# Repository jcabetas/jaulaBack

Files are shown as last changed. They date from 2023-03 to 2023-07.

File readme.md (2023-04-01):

# Alimentador de gatos

## Sistema operativo
ChibiOS/RT port for ARM-Cortex-M4 STM32F411.

## uControlador
Datos en https://stm32-base.org/boards/STM32F411CEU6-WeAct-Black-Pill-V2.0.html

## Conexiones
- A1: Sensor 1
- A2: Sensor 2
- A2: TX2 (a RX Configuracion)
- A3: RX2 (a TX Configuracion)
- A9: TX1 (a GPS)
- A10: RX1 (a GPS)
- B0: ADC in divide Ubat por 220/(220+91)
- B8: PWM para Servo
- B13: ONGPS
- B14: ONSERVO
- B15: ON-AD

w25q16
- CS -   PA4
- SCK -  PA5    SPI1_SCK
- MISO - PA6    SPI1_MISO
- MOSI - PA7    SPI1_MOSI

## Parametros
* Las configuraciones se guardan en flash

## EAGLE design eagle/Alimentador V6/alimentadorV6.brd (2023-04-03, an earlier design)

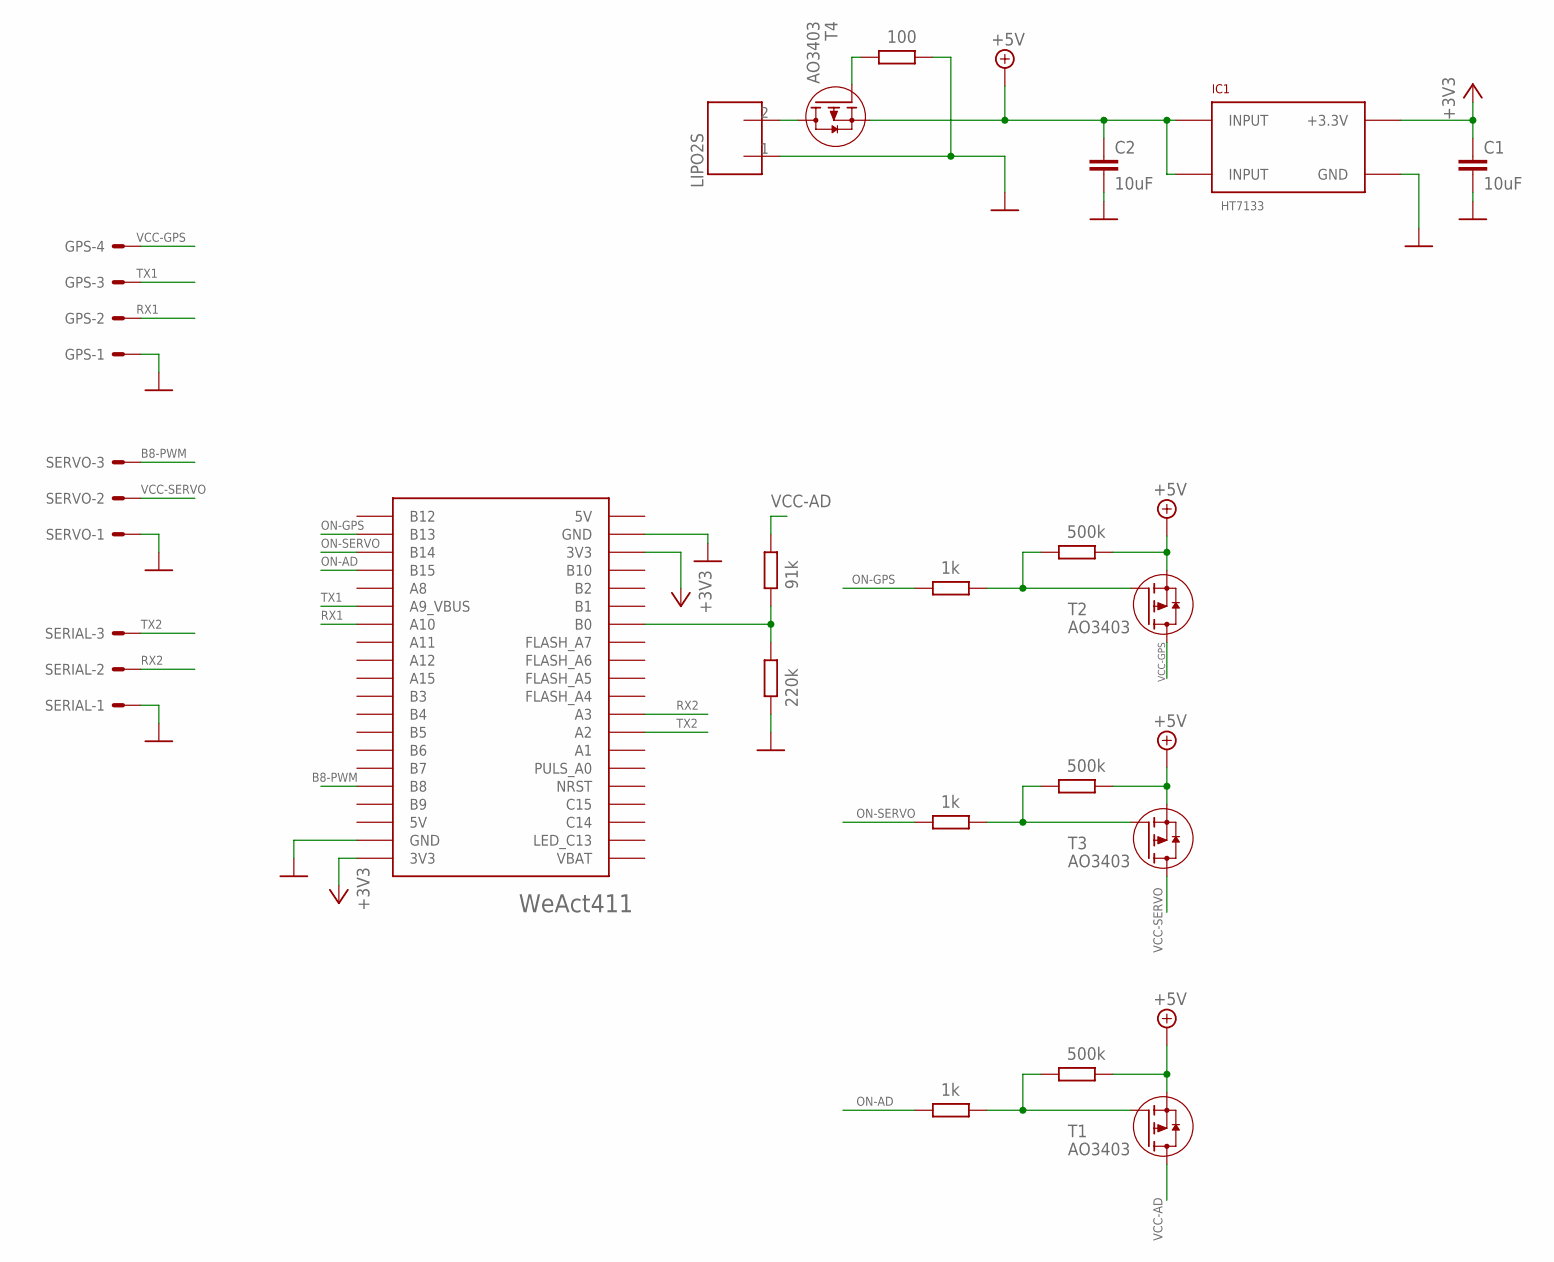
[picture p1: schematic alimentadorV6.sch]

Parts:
C1, C2: 10uF; C1206
GPS: 22-27-2041-04; 6410-04
IC1: HT7133; SOT89
LIPO2S: CONECTOR_2P-3.81; CON2P-3.81
R1, R5, R11: 500k; R1206
R2: 220k; R1206
R3: 91k; R1206
R4, R6, R12: 1k; R1206
R7: 100; R1206
SERIAL: 22-27-2031-03; 6410-03
SERVO: 22-27-2031-03; 6410-03
T1, T2, T3, T4: AO3403; SOT23
U$2: WEACT411

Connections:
+3V3: C1.1, IC1.3 (+3.3V), U$2.3V3@1 (3V3), U$2.3V3@2 (3V3)
+5V: C2.1, IC1.2 (INPUT), IC1.4 (INPUT), R1.2, R5.2, R11.2, T1.2 (S), T2.2 (S), T3.2 (S), T4.2 (S)
B8-PWM: SERVO.3, U$2.B8
GND: C1.2, C2.2, GPS.1, IC1.1 (GND), LIPO2S.1, R2.2, R7.2, SERIAL.1, SERVO.1, U$2.GND@1 (GND), U$2.GND@2 (GND)
unnamed: LIPO2S.2, T4.3 (D)
unnamed: R2.1, R3.2, U$2.B0
unnamed: R7.1, T4.1 (G)
unnamed: R1.1, R4.2, T2.1 (G)
unnamed: R11.1, R12.2, T1.1 (G)
unnamed: R5.1, R6.2, T3.1 (G)
ON-AD: R12.1, U$2.B15
ON-GPS: R4.1, U$2.B13
ON-SERVO: R6.1, U$2.B14
RX1: GPS.2, U$2.A10
RX2: SERIAL.2, U$2.A3
TX1: GPS.3, U$2.A9 (A9_VBUS)
TX2: SERIAL.3, U$2.A2
VCC-AD: R3.1, T1.3 (D)
VCC-GPS: GPS.4, T2.3 (D)
VCC-SERVO: SERVO.2, T3.3 (D)

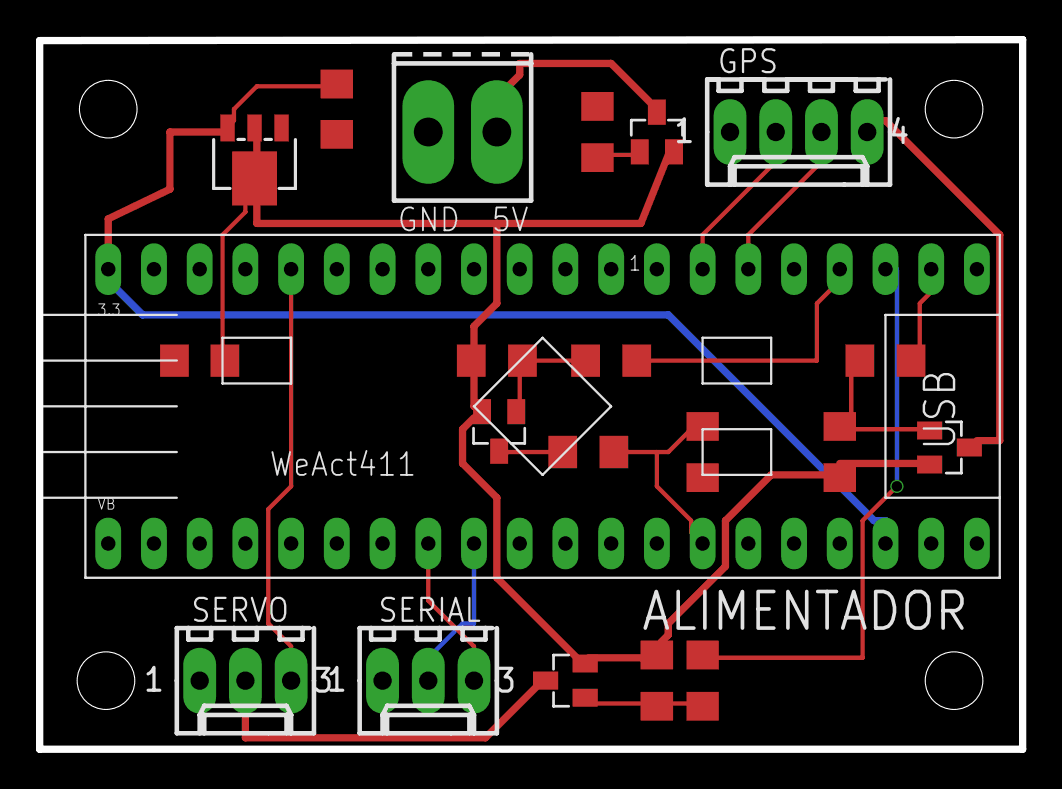
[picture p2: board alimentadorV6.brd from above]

Board: 2 copper layers, 54.6 x 39.4 mm, 21 parts (0 on the bottom side), 20 nets.

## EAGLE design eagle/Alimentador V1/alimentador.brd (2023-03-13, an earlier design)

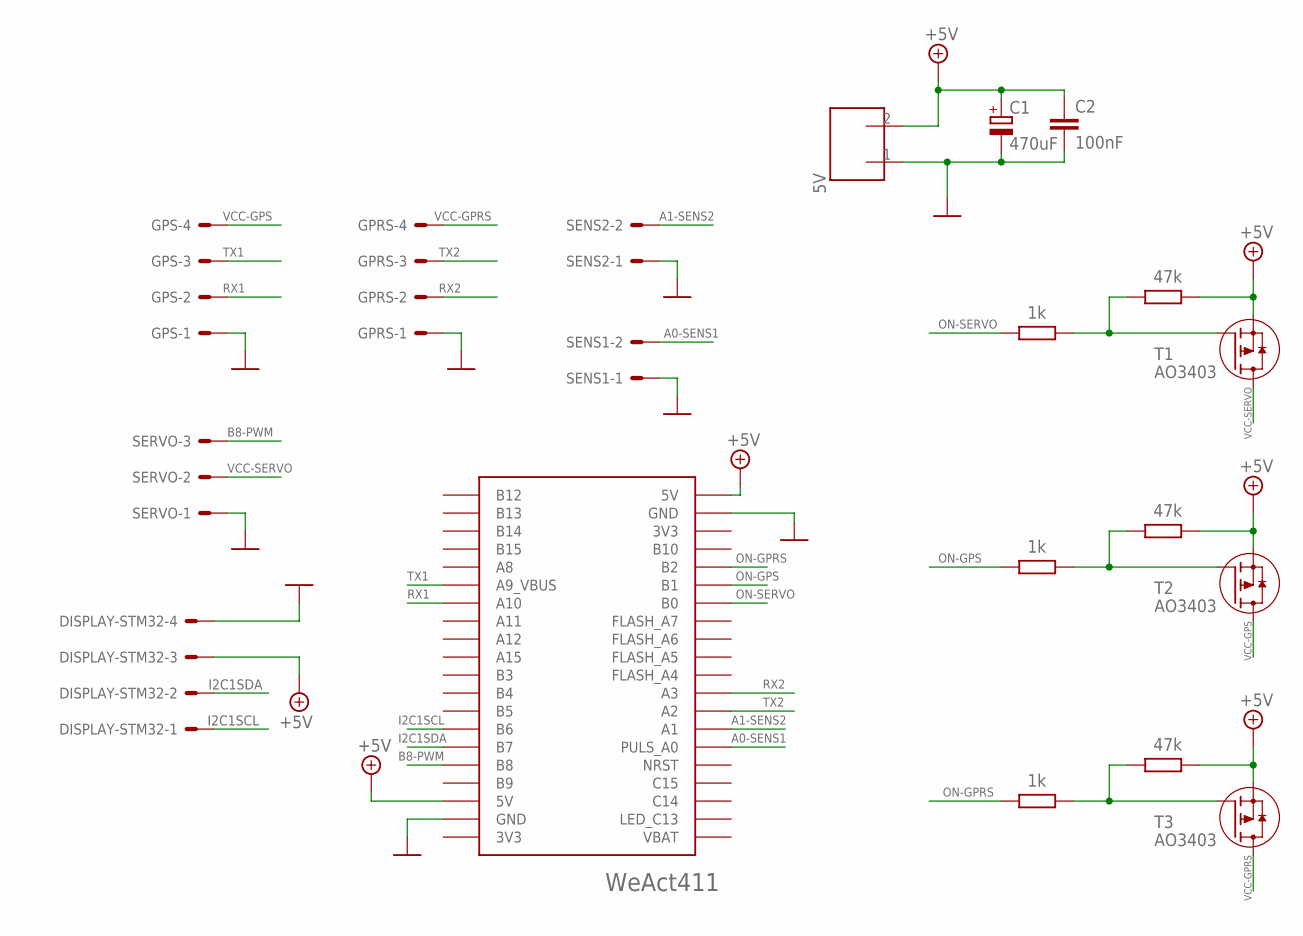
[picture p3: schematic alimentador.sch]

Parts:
5V: CONECTOR_2P-3.81; CON2P-3.81
C1: 470uF; E5-10,5
C2: 100nF; C1206
DISPLAY-STM32: 22-05-7048-04; 7395-04
GPRS: 22-27-2041-04; 6410-04
GPS: 22-27-2041-04; 6410-04
R1, R2, R5: 47k; R1206
R3, R4, R6: 1k; R1206
SENS1, SENS2: 22-27-2021-02; 6410-02
SERVO: 22-27-2031-03; 6410-03
T1, T2, T3: AO3403; SOT23
U$2: WEACT411

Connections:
+5V: 5V.2, C1.+, C2.1, DISPLAY-STM32.3, U$2.5V@1 (5V), U$2.5V@2 (5V)
A0-SENS1: SENS1.2, U$2.A0 (PULS_A0)
A1-SENS2: SENS2.2, U$2.A1
B8-PWM: SERVO.3, U$2.B8
GND: 5V.1, C1.-, C2.2, DISPLAY-STM32.4, GPRS.1, GPS.1, SENS1.1, SENS2.1, SERVO.1, U$2.GND@1 (GND), U$2.GND@2 (GND)
I2C1SCL: DISPLAY-STM32.1, U$2.B6
I2C1SDA: DISPLAY-STM32.2, U$2.B7
unnamed: R2.2, T1.2 (S)
unnamed: R2.1, R3.2, T1.1 (G)
unnamed: R1.2, T2.2 (S)
unnamed: R1.1, R4.2, T2.1 (G)
unnamed: R5.2, T3.2 (S)
unnamed: R5.1, R6.2, T3.1 (G)
ON-GPRS: R6.1, U$2.B2
ON-GPS: R4.1, U$2.B1
ON-SERVO: R3.1, U$2.B0
RX1: GPS.2, U$2.A10
RX2: GPRS.2, U$2.A3
TX1: GPS.3, U$2.A9 (A9_VBUS)
TX2: GPRS.3, U$2.A2
VCC-GPRS: GPRS.4, T3.3 (D)
VCC-GPS: GPS.4, T2.3 (D)
VCC-SERVO: SERVO.2, T1.3 (D)

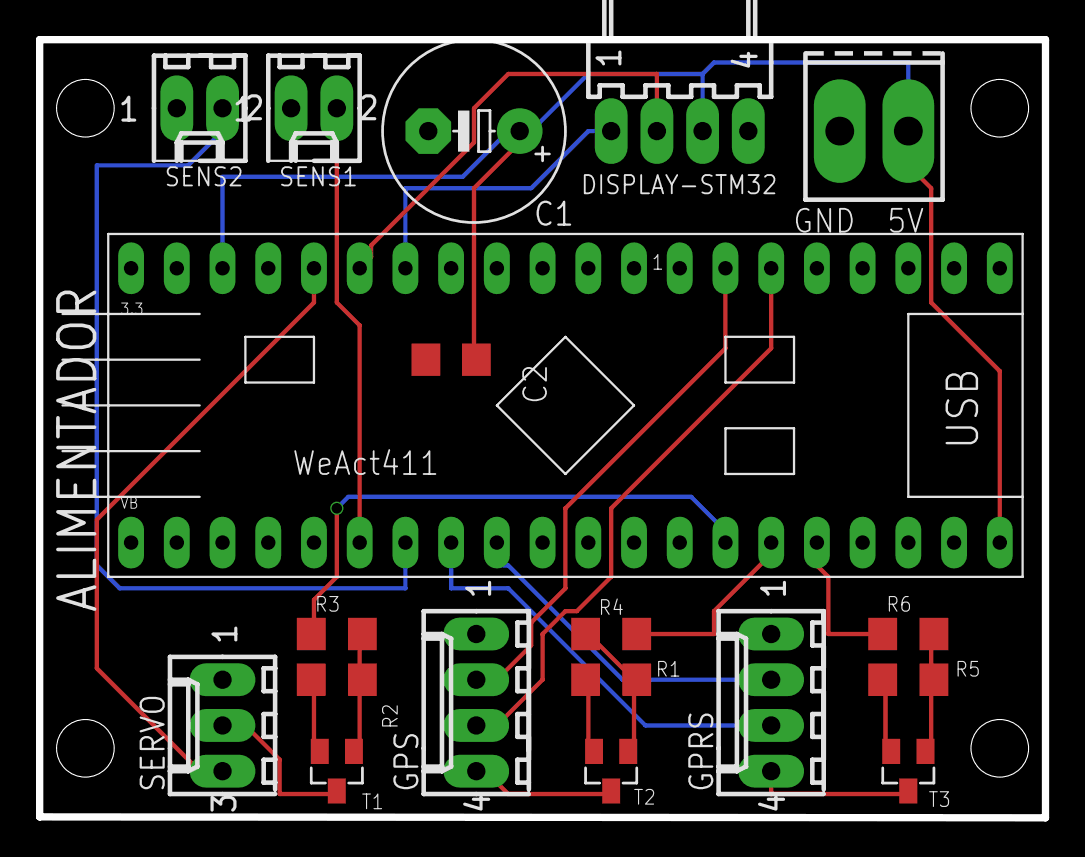
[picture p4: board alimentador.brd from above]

Board: 2 copper layers, 55.9 x 43.2 mm, 19 parts (0 on the bottom side), 23 nets.

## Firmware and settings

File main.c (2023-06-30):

/*
 ChibiOS - Copyright (C) 2006..2018 Giovanni Di Sirio

 Licensed under the Apache License, Version 2.0 (the "License");
 you may not use this file except in compliance with the License.
 You may obtain a copy of the License at

 http://www.apache.org/licenses/LICENSE-2.0

 Unless required by applicable law or agreed to in writing, software
 distributed under the License is distributed on an "AS IS" BASIS,
 WITHOUT WARRANTIES OR CONDITIONS OF ANY KIND, either express or implied.
 See the License for the specific language governing permissions and
 limitations under the License.
 */

#include "ch.h"
#include "hal.h"
#include "alimCalle.h"
#include "chprintf.h"


extern uint8_t enHora, hayUbicacion;
extern uint8_t GL_Flag_External_WakeUp;

/*
 * Alimentador de gatos
 *
 * BUCLE
 * Si es el primer arranque, pon RTC en hora con GPS
 * Para cualquier arranque
 * - leer variables
 * - lee la hora del RTC
 * - bucle:
 *      - Situar la puerta con la logica definida
 *      - Analizar segundos que faltan para cambiar de estado
 *      - Si el dia del año difiere, actualizar hora de amanecer
 *
 * HARDWARE
 * - Blackpill
 * - Pin A0 Sensor 1
 * - Pin A1 Sensor 2
 * - Pin A2 (GPIOB_TX2) TX para GPRS
 * - Pin A3 (GPIOB_RX2) RX para GPRS
 * - Pin A9 (GPIOB_TX1) TX para GPS
 * - Pin A10 (GPIOB_RX1) RX para GPS
 * - Pin B0 (GPIOB_ONSERVO) low activa tension al servo
 * - Pin B1 (GPIOB_ONGPS) low activa GPS
 * - Pin B2 (GPIOB_ONGPRS) low activa GPRS
 * - Pin B8 (GPIOB_PWMSERVO) salida PWM al servo en TIM4CH2
 * - Pin C13 (GPIOC_LED) es el led de la placa, activo Lowvoid opciones(void)
 * - Pin A0 (GPIOA_KEY) es pulsador KEY para despertar a la placa
 */

// Consumo: usando regulador HT7333 consigo 12 uA en placa

volatile uint8_t msDelayLed = 1;
volatile uint16_t numCuentas;
extern uint16_t autoPuerta; // 0:cerrada, 1:abierta, 2: automatico, 3: autoConMargen
extern int16_t dsAddPordia;
extern uint32_t secAdaptacion;
extern uint8_t hayGps;

void parpadear(uint8_t numVeces, uint16_t ms) {
    palSetPadMode(GPIOC, GPIOC_LED, PAL_MODE_OUTPUT_PUSHPULL);
    for (uint8_t i = 0; i < numVeces; i++) {
        palClearPad(GPIOC, GPIOC_LED); // enciende led placa
        chThdSleepMilliseconds(10);
        palSetPad(GPIOC, GPIOC_LED); // apaga led placa
        chThdSleepMilliseconds(ms);
    }
    palSetPadMode(GPIOC, GPIOC_LED, PAL_MODE_INPUT_ANALOG);
}


int main(void) {
    uint8_t estDes;
    uint32_t sec2change;
    char buffer[90], buff[50];
    halInit();
    chSysInit();
    initSerial();
    parpadear(2, 250);
    leeVariablesC();
    ajustaCALMP_C(dsAddPordia);
    if (autoPuerta != 3)
        secAdaptacion = 0;
    hayGps = 1; // supongo que hay GPS
    printSerial("Inicializado\n\r");
    abrePuertaC();
    chThdSleepMilliseconds(2000);
    cierraPuertaC();
    while (1 == 1) {
        leeVariablesC();
        leeGPS();
        leeHora();
        printFechaC(buff, sizeof(buff));
        chsnprintf(buffer, sizeof(buffer), "Fecha actual UTC: %s  CALR:%d\n\r", buff, RTCD1.rtc->CALR);
        printSerial(buffer);
        estadoDeseadoPuertaC(&estDes, &sec2change);
        chsnprintf(buffer, sizeof(buffer),
                   "Main, auto puerta:%d estado puerta:%d, cambio en %d s\n\r",
                   autoPuerta, estDes, sec2change);
        printSerial(buffer);
        if (estDes == 1)
            abrePuertaC();
        else
            cierraPuertaC();
        chsnprintf(buffer, sizeof(buffer), "A dormir %d s\n\r", sec2change);
        printSerial(buffer);
        ports_set_lowpower();
        stop(sec2change);
        if (GL_Flag_External_WakeUp == 0) {
            parpadear(1, 100);
            printSerial("Timeout desde stop\n\r");
        }
        else if (GL_Flag_External_WakeUp == 1) {
            opciones();
        }
        else if (GL_Flag_External_WakeUp == 2) {
            abrePuertaHastaA1C();
        }
    }
}

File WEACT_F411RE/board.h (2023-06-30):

/*
    ChibiOS - Copyright (C) 2006..2018 Giovanni Di Sirio

    Licensed under the Apache License, Version 2.0 (the "License");
    you may not use this file except in compliance with the License.
    You may obtain a copy of the License at

        http://www.apache.org/licenses/LICENSE-2.0

    Unless required by applicable law or agreed to in writing, software
    distributed under the License is distributed on an "AS IS" BASIS,
    WITHOUT WARRANTIES OR CONDITIONS OF ANY KIND, either express or implied.
    See the License for the specific language governing permissions and
    limitations under the License.
*/

/*
 * This file has been automatically generated using ChibiStudio board
 * generator plugin. Do not edit manually.
 */

#ifndef BOARD_H
#define BOARD_H

/*===========================================================================*/
/* Driver constants.                                                         */
/*===========================================================================*/

/*
 * Setup for STMicroelectronics STM32 Nucleo64-F411RE board.
 */

/*
 * Board identifier.
 */
#define BOARD_ST_NUCLEO64_F411RE
#define BOARD_NAME                  "BlackPill WeAct F411CEU6"

/*
 * Board oscillators-related settings.
 */
#if !defined(STM32_LSECLK)
#define STM32_LSECLK                32768U
#endif

#if !defined(STM32_HSECLK)
#define STM32_HSECLK                25000000U
#endif

//#define STM32_HSE_BYPASS

/*
 * Board voltages.
 * Required for performance limits calculation.
 */
#define STM32_VDD                   300U

/*
 * MCU type as defined in the ST header.
 */
#define STM32F411xE

#define ALIMV7

#ifdef ALIMV7
#define ACTIVAPAD palSetPad
#define QUITAPAD  palClearPad
#else
#define ACTIVAPAD palClearPad
#define QUITAPAD  palSetPad
#endif

/*
 * IO pins assignments.
 */

#define GPIOA_KEY                    0U
#define GPIOA_SENS2                  1U
#define GPIOA_TX2                    2U
#define GPIOA_RX2                    3U
#define GPIOA_W25Q16_CS              4U
#define GPIOA_SPI1_SCK               5U
#define GPIOA_SPI1_MISO              6U
#define GPIOA_SPI1_MOSI              7U
#define GPIOA_PIN8                   8U
#define GPIOA_PULSOSGPS              9U
#define GPIOA_RX1                   10U
#define GPIOA_OTG_FS_DM             11U
#define GPIOA_OTG_FS_DP             12U
#define GPIOA_SWDIO                 13U
#define GPIOA_SWCLK                 14U
#define GPIOA_PIN15                 15U

#define GPIOB_VBAT                   0U
#define GPIOB_PIN1                   1U
#define GPIOB_PIN2                   2U
#define GPIOB_PIN3                   3U
#define GPIOB_PIN4                   4U
#define GPIOB_PIN5                   5U
#define GPIOB_I2C1SCL                6U
#define GPIOB_I2C1SDA                7U
#define GPIOB_PWMSERVO               8U
#define GPIOB_PIN9                   9U
#define GPIOB_PIN10                 10U
#define GPIOB_PIN11                 11U
#define GPIOB_PIN12                 12U
#define GPIOB_ONGPS                 13U
#define GPIOB_ONSERVO               14U
#define GPIOB_ONAD                  15U

#define GPIOC_ARD_A5                0U
#define GPIOC_ADC1_IN10             0U
#define GPIOC_ARD_A4                1U
#define GPIOC_ADC1_IN11             1U
#define GPIOC_PIN2                  2U
#define GPIOC_PIN3                  3U
#define GPIOC_PIN4                  4U
#define GPIOC_PIN5                  5U
#define GPIOC_PIN6                  6U
#define GPIOC_ARD_D9                7U
#define GPIOC_PIN8                  8U
#define GPIOC_PIN9                  9U
#define GPIOC_PIN10                 10U
#define GPIOC_PIN11                 11U
#define GPIOC_PIN12                 12U
#define GPIOC_LED                   13U
#define GPIOC_OSC32_IN              14U
#define GPIOC_OSC32_OUT             15U

#define GPIOD_PIN0                  0U
#define GPIOD_PIN1                  1U
#define GPIOD_PIN2                  2U
#define GPIOD_PIN3                  3U
#define GPIOD_PIN4                  4U
#define GPIOD_PIN5                  5U
#define GPIOD_PIN6                  6U
#define GPIOD_PIN7                  7U
#define GPIOD_PIN8                  8U
#define GPIOD_PIN9                  9U
#define GPIOD_PIN10                 10U
#define GPIOD_PIN11                 11U
#define GPIOD_PIN12                 12U
#define GPIOD_PIN13                 13U
#define GPIOD_PIN14                 14U
#define GPIOD_PIN15                 15U
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

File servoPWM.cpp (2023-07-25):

/*
 * pwmInts.c
 *
 *  Created on: 03/06/2012, adaptado 15/11/2015 a Flip32,
 *  adaptado y muy simplificado para BlackPill 20/9/2022
 *      Author: joaquin
 *  Salida servo 1  (PWM1, PB6, TIM4_CH1, AF02)
 */

#include "hal.h"
#include "chprintf.h"

extern "C" {
    void mueveServoPosC(uint16_t porcPosicion);
    void cierraPuertaC(void);
    void abrePuertaC(void);
    void abrePuertaHastaA1C(void);
}
void printSerialCPP(const char *msg);

extern uint16_t posAbierto;
extern uint16_t posCerrado;
uint16_t porcPosAnterior = 50;

static PWMConfig pwmcfg = {
  3125000, /* 48 MHz PWM clock frequency */
    62500,   /* PWM period 20 millisecond */
  NULL,  /* No callback */
  /* Channel 4 enabled */
  {
    {PWM_OUTPUT_DISABLED, NULL},
    {PWM_OUTPUT_DISABLED, NULL},
    {PWM_OUTPUT_ACTIVE_HIGH, NULL},
    {PWM_OUTPUT_DISABLED, NULL},
  },
  0,
  0,
  0
};

bool tensionCritica(void);


void initServo(void)
{
/*
 *   Salida servo: TIM4CH3 (PB8)
 */
    palSetPadMode(GPIOB, GPIOB_PWMSERVO,PAL_MODE_ALTERNATE(2) | PAL_STM32_OSPEED_HIGHEST);
    palSetPadMode(GPIOB, GPIOB_ONSERVO, PAL_MODE_OUTPUT_PUSHPULL);
    ACTIVAPAD(GPIOB, GPIOB_ONSERVO);
	pwmStart(&PWMD4, &pwmcfg);
}

void closeServo(void)
{
    palSetPadMode(GPIOB, GPIOB_PWMSERVO,PAL_MODE_INPUT_ANALOG );
    QUITAPAD(GPIOB, GPIOB_ONSERVO);
    pwmStop(&PWMD4);
}

void mueveServoAncho(uint16_t ancho, uint16_t ms)
{
  // minimo 2980, maximo 6068, medio 4529
  if (ancho<2700) ancho=2700;
  if (ancho>6500) ancho=6500;
  pwmEnableChannel(&PWMD4, 2, ancho);
  chThdSleepMilliseconds(ms);
}

void mueveServoPos(uint16_t porcPosicion)
{
  uint16_t ancho;
  // arranco servo
  initServo();
  ACTIVAPAD(GPIOB, GPIOB_ONSERVO);
  if (PWMD4.state==PWM_STOP)
      pwmStart(&PWMD4, &pwmcfg);
  if (porcPosicion>100) porcPosicion=100;
  // si esta en la posicion, recordar durante 1500ms
  if (porcPosicion==porcPosAnterior)
  {
      ancho = (uint16_t) (2700.0f+3800.0f*porcPosicion/100.0f);
      mueveServoAncho(ancho, 1500);
      closeServo();
      return;
  }
  if (porcPosicion>porcPosAnterior)
  {
      for (int16_t pos=porcPosAnterior;pos<=porcPosicion;pos++)
      {
          ancho = (uint16_t) (2700.0f+3800.0f*pos/100.0f);
          mueveServoAncho(ancho, 15);
      }
      mueveServoAncho(ancho, 500);
      porcPosAnterior = porcPosicion;
      closeServo();
      return;

  }
  if (porcPosicion<porcPosAnterior)
  {
      for (int16_t pos=porcPosAnterior;pos>=porcPosicion;pos--)
      {
          ancho = (uint16_t) (2700.0f+3800.0f*pos/100.0f);
          mueveServoAncho(ancho, 15);
      }
      mueveServoAncho(ancho, 500);
      porcPosAnterior = porcPosicion;
      closeServo();
      return;
  }
}

void mueveServoPosC(uint16_t porcPosicion)
{
    mueveServoPos(porcPosicion);
}

void cierraPuertaC(void)
{
    if (tensionCritica())
        return;
    if (posCerrado==porcPosAnterior)
    {
        // recuerda posicion
        mueveServoPos(posCerrado);
        return;
    }
    uint16_t posIntermedia = posAbierto + ((posCerrado - posAbierto)>>2);
    mueveServoPos(posIntermedia);
    chThdSleepMilliseconds(1500);
    mueveServoPos(posCerrado);
}

void abrePuertaC(void)
{
    mueveServoPos(posAbierto);
}

void cierraPuerta(void)
{
    cierraPuertaC();
}


void abrePuertaHastaA1C(void)
{
    printSerialCPP("Cerrado sensor\n\r");
    chThdSleepMilliseconds(200);  // compruebo que no es esporadico (p.e. vibracion en sensor)
    if (palReadPad(GPIOA, GPIOA_SENS2))
    {
        printSerialCPP("Era falso, no hago nada\n\r");
        return;
    }
    mueveServoPos(posAbierto);
    // espera a dejar de pulsar A1 para salir, con 10 minutos de timeout
    for (uint16_t ds=0;ds<6000;ds++)
    {
        if (palReadPad(GPIOA, GPIOA_SENS2))
            return;
        chThdSleepMilliseconds(100);
    }
    return;
}

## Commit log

2021-02-07 Desde HSI sin USB: 2.5 mA
2021-02-07 Con HSE 3.6 mA
2021-02-14 Midiendo bateria
    Tambien temperatura, salen cosas raras (falta ajustar tiempo muestreo de
    temperatura)
2021-02-21 Implementado sensor de jaula con interrupciones
    Ahora hay que engancharlo con SMS
2021-02-21 Con % de batería correcto
    [adcUtils.cpp]
2021-02-28 Con el estado en los mensajes
2021-03-07 Con led de alarma separada
2022-09-30 La prueba de sleep funciona (parece)
2022-10-01 Quitando deepsleep funciona
    Hay que ir probando poco a poco
2022-10-03 El modo stop con 26 uA parece que pita
2022-10-20 Con control de fase
2023-01-17 Lee del GPS la hora
2023-01-19 Funciona, pero con consumo de 350 uA
2023-01-24 Corregido ancho de servo y otros
2023-03-13 Ya con configuracion y servo
    Queda solo la adaptacion automatica
    [alimentador.brd, alimentador.sch, alimentadorV2.brd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]
2023-03-14 Con correcion desvio de hora y errores varios
    [main.c, serial.cpp, variables.cpp]
2023-03-15 Con posiciones de servo
    [alimentadorV5.brd, alimentadorV5.sch]
2023-03-16 Con escalon antes de cerrar y error en flash
    [main.c, serial.cpp, servoPWM.cpp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]
2023-03-29 Considero sleeps de más de 8 horas
2023-03-29 Cálculo de horas
    [Comprobacion rutinas.ods]
2023-04-01 Con lectura tension (no cierra si queda poca bateria)
2023-04-03 No consigo bajar el consumo
    [alimentadorV5.brd, alimentadorV5.sch, alimentadorV6.brd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]
2023-04-03 Resuelto misterio consumo
    Regulador original era una castaña, con el HT7333 consigo 12 uA en la
    placa
    [alimentadorV6.brd, alimentadorV6.sch]
2023-04-23 Corregido inicialización de adaptacion no deseada
2023-04-25 Enseñar dia actualizacion de fecha
    Se va demasiado de la hora, no acabo de entender porqué
2023-04-29 Cuando se ponía en hora, añadía la compensación de forma errónea
2023-04-29 Ajuste RTC usando registro CAL en vez de desvios diarios
2023-04-30 Usar el pin de TXGPS como entrada de pulsos
2023-04-30 Algunos temas de que no reconoce el wakeup a veces
2023-05-03 Corregido el que no despertaba con boton
    Las rutinas de Chibios parten del hecho de que el RTC está con
    proteccion escritura quietada
2023-05-03 Movimiento progresivo del servo
2023-05-04 Vuelvo a cerrar en dos fases, para no pillar gatos
2023-05-04 Con reset abre y cierra puerta, para probar
    [main.c]
2023-05-26 Default para retraso en anochecer = -30
2023-06-03 Configuración del ADC corregida y pulsar A1 para abrir
    Estaba mal configurado el tiempo de muestreo, ha mejorado radicalmente.
    El pulsar A1 sirve para comprobar la puerta y limpiar
2023-06-11 Al arrancar GPS sin conectarse, recibe pulsos espúreos que bloquean el arranque. También nueva version en eagle
    [alimentadorV7.brd, alimentadorV7.sch]
